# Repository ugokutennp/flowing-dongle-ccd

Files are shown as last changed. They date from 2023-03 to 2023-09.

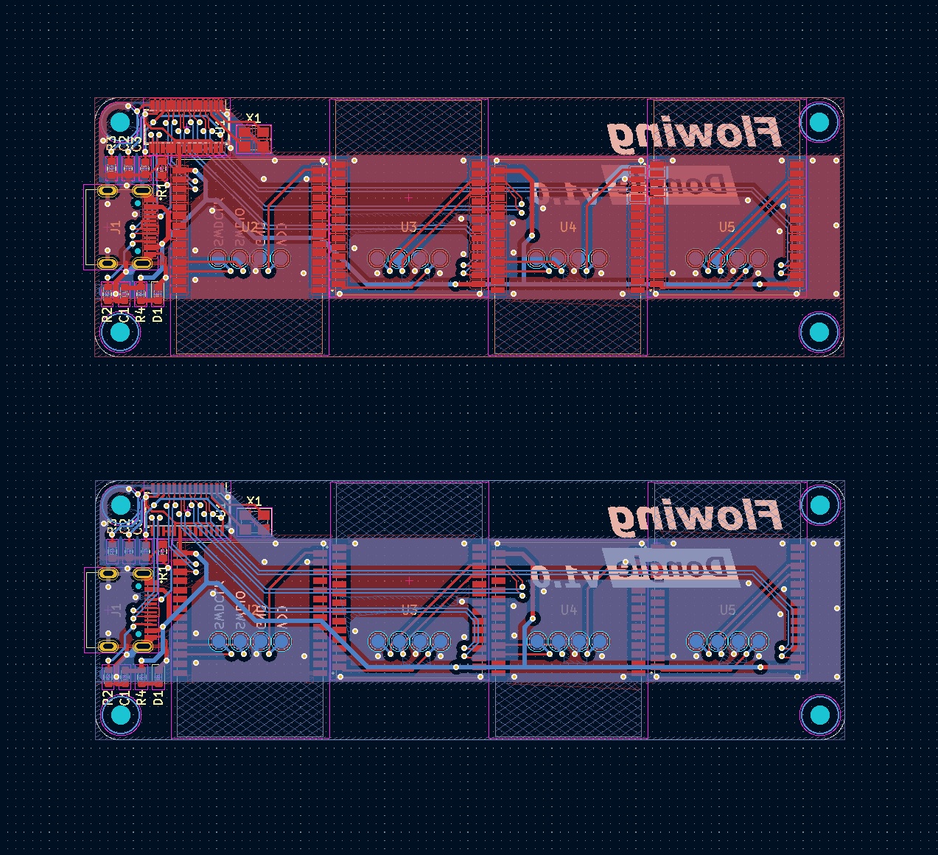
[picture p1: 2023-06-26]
images/flowing_dongle_pcb.jpg

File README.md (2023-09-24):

# FlowingDongleCCD
DIY Multiple Connection Watchman Dongle for SteamVR
dongle
FlowingDongle is a very simple dongle for SteamVR that can connect four devices simultaneously with a built-in nrf52840 module and a USB hub.
## Hardware
Includes PCB data created in kicad6 and 3D model data of the case.
The main components are made of the following.
|| components |
|--|--|
| USB 2.0 Hub Controller |FE1.1s  |
|nrf52840 module| MS88SF2 |

BOM can be viewed [here](https://htmlpreview.github.io/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).
The PCB design and schematic is minimal and not perfect, although stable operation has been confirmed.

[schematic](https://github.com/ugokutennp/FlowingDongleCCD/blob/main/images/flowing_dongle_schematic.pdf),
[pcb_design](https://github.com/ugokutennp/FlowingDongleCCD/blob/main/images/flowing_dongle_pcb.jpg)

## Firmware
By writing the four hex files via SWD using a device such as Jlink, it can be used immediately as a Watchman Dongle.
Firmware comes from the following locations.
| |  name |  place |
|---|---|---|
| Bootloader  |  nrf52840_xxaa_debug.hex |  nRF5_SDK_17.1.0_ddde560\examples\dfu\open_bootloader\pca10056_usb_debug\armgcc |
|  MBR |  mbr_nrf52_2.4.1_mbr.hex | nRF5_SDK_17.1.0_ddde560\components\softdevice\mbr\hex  | 
|  SoftDevice |  s140_nrf52_6.1.1_softdevice.bin |  C:\Program Files (x86)\Steam\steamapps\common\SteamVR\drivers\indexhmd\resources\firmware\radio\gd_1558748372_dfu | 
| Application  |  temp_app_stamped.bin |  C:\Program Files (x86)\Steam\steamapps\common\SteamVR\drivers\indexhmd\resources\firmware\radio\gd_1558748372_dfu | 

## Bootloader build
Install [Make for Windows](https://gnuwin32.sourceforge.net/packages/make.htm) and Arm Embedded Toolchain ([gcc-arm-none-eabi-9-2020-q2-update-win32.exe](https://developer.arm.com/downloads/-/gnu-rm)) and build with the following command.

    cd Desktop\nRF5_SDK_17.1.0_ddde560\examples\dfu\open_bootloader\pca10056_usb_debug\armgcc
    make

## IndexHMD firmware optimization
Open temp_app_stamped.bin with a hex editor and edit the following items.
| adress  |  before |  after | effect |
|---|---|---|---|
| 0x1839D  |  B1|B9 |disable index audio device |
|  0x162E0 |  Valve VR Radio | any string you like| rename USB device|

## Firmware conversion (bin to hex)
Convert firmware using [srec_cat_exe](https://sourceforge.net/projects/srecord/files/srecord-win32/).

    cd C:\Users\marim\Desktop\Dongle\gd_1558748372_dfu
    srec_cat.exe s140_nrf52_6.1.1_softdevice.bin -Binary -offset 0x1000 -o s140_nrf52_6.1.1_softdevice.hex -Intel
    srec_cat.exe temp_app_stamped.bin -Binary -offset 0x26000 -o temp_app_stamped.hex -Intel
## License
The license applies to hardware data only.

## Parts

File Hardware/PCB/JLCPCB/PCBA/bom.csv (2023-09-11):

Designator | Footprint | Quantity | Value | LCSC Part #
C1, C2, C3 | 0603 | 3 | 10uF
D1 | 0603 | 1 | LED
J1 | HRO_TYPE-C-31-M-12 | 1 | TYPE-C-31-M-12
R1, R2 | 0603 | 2 | 5.1k
R3 | 0603 | 1 | 2.7kΩ(+-1%)
R4 | 0603 | 1 | R
U1 | SSOP-28_3.9x9.9mm_P0.635mm | 1 | FE1.1s
U2, U3, U4, U5 | XCVR_MS88SF2 | 4 | MS88SF2
X1 | Crystal_SMD_3225-4Pin_3.2x2.5mm | 1 | 12MHz

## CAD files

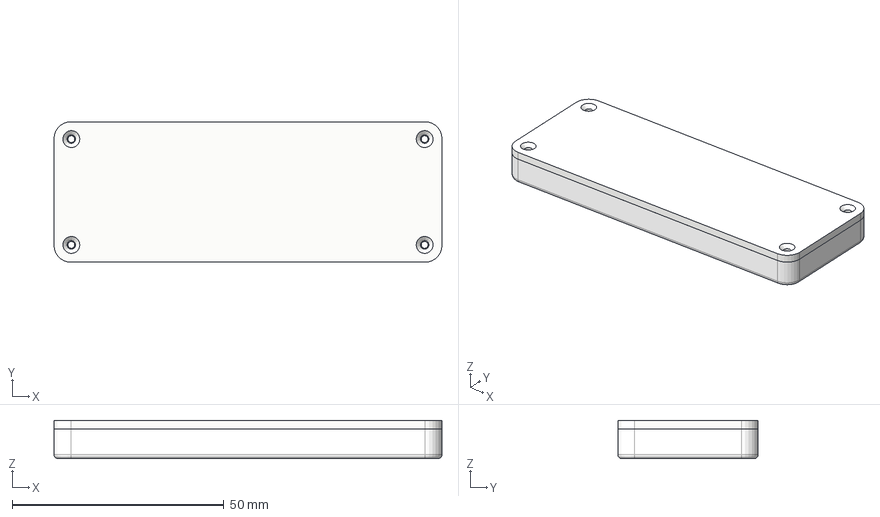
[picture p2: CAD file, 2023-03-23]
Hardware/Case/flowing_dongle v16.step
91.7 x 33.2 x 9.06 mm
_autosave-flowing_dongle PCB

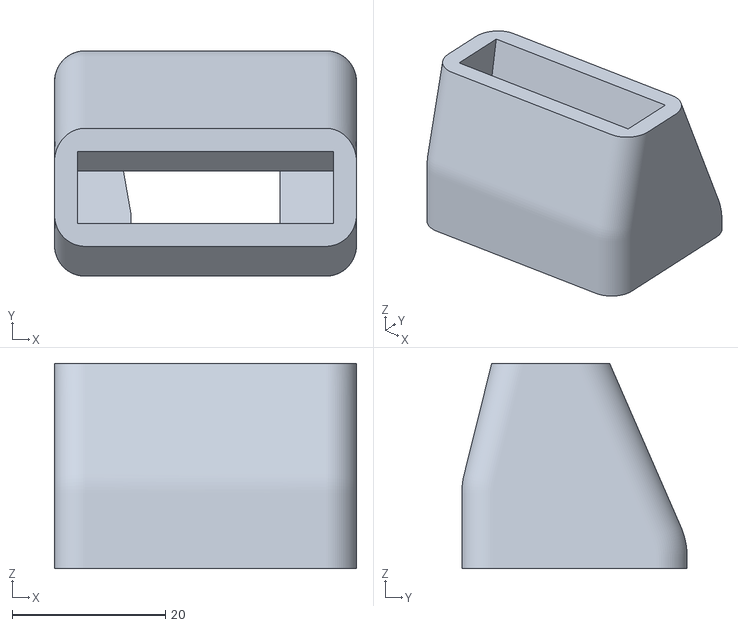
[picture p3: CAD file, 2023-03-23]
Hardware/Case/STL/cradle.stl
39.4 x 29.4 x 26.8

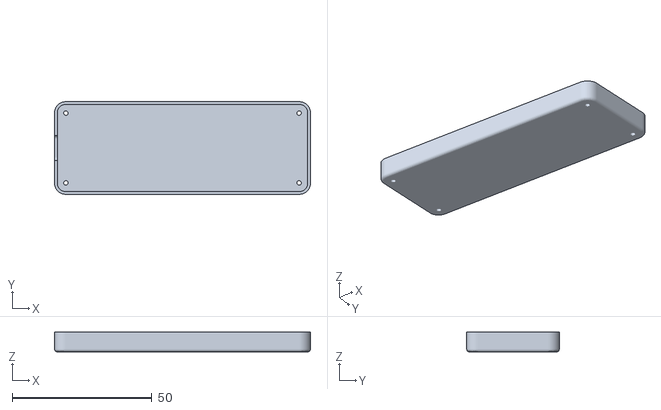
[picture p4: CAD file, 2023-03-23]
Hardware/Case/STL/case.stl
91.7 x 33.2 x 7.06

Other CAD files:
Hardware/Case/cradle v6.step

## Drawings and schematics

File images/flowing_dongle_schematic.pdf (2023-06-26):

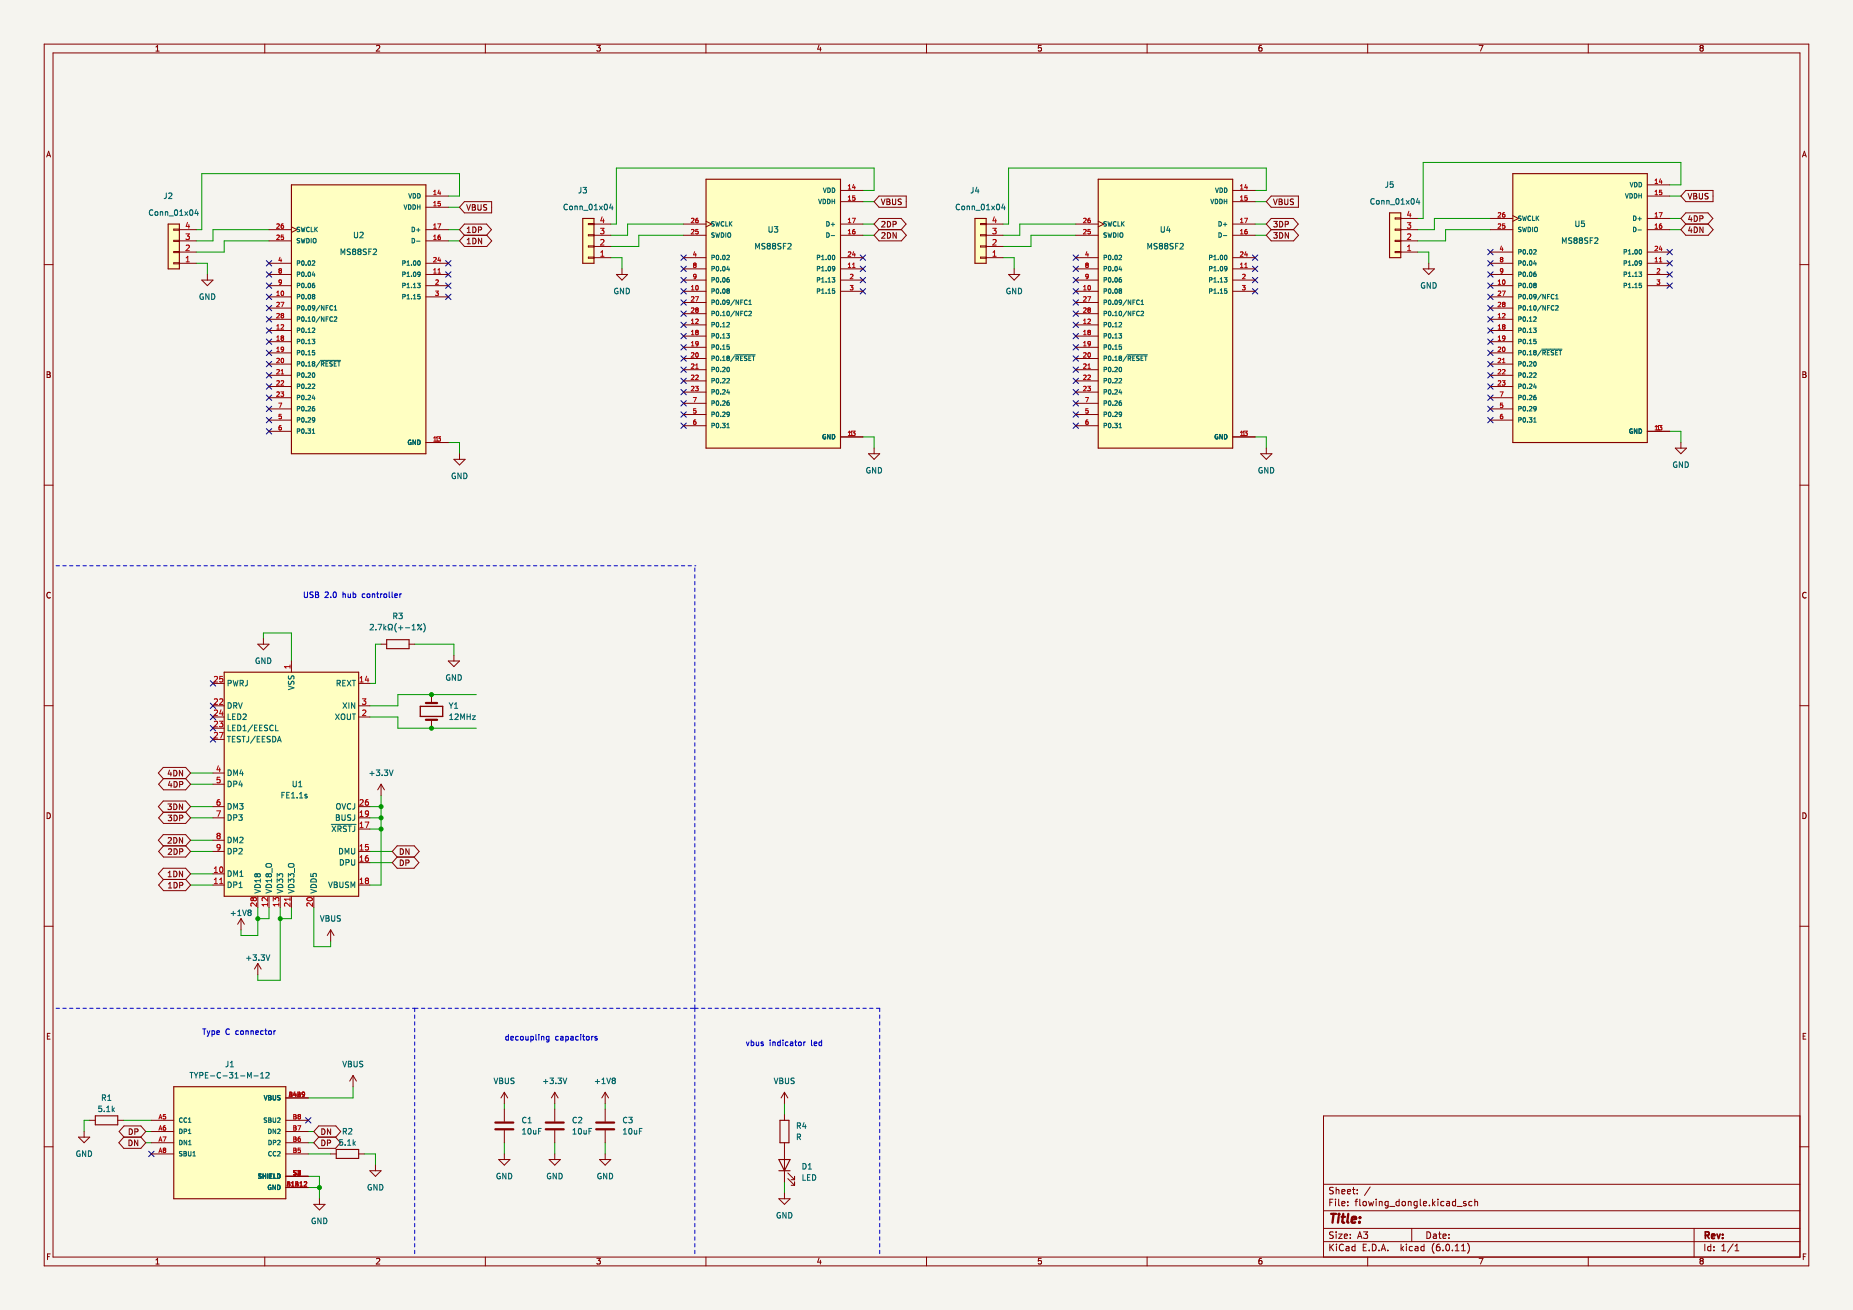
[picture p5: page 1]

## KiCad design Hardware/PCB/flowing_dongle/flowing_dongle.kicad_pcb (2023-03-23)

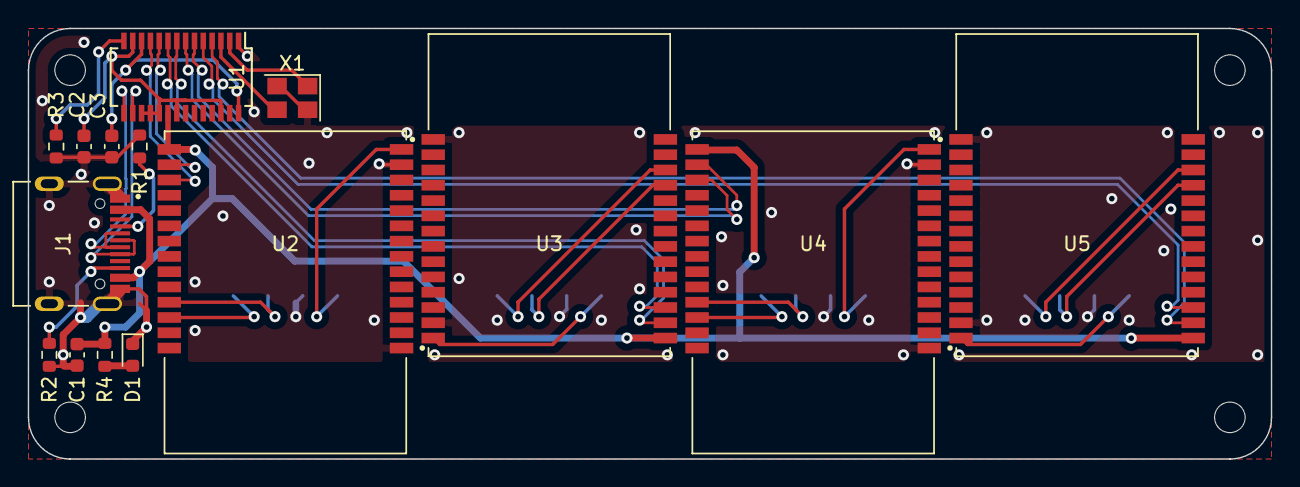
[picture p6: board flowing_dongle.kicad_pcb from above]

Board: 2 copper layers, 89.5 x 31.0 mm, 15 parts (0 on the bottom side), 20 nets.

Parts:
C1, C2, C3: 10uF; C_0603_1608Metric
D1: LED; LED_0603_1608Metric
J1: TYPE-C-31-M-12; HRO_TYPE-C-31-M-12
R1, R2: 5.1k; R_0603_1608Metric
R3: 2.7kΩ(+-1%); R_0603_1608Metric
R4: R; R_0603_1608Metric
U1: FE1.1s; SSOP-28_3.9x9.9mm_P0.635mm
U2, U3, U4, U5: MS88SF2; XCVR_MS88SF2
X1: 12MHz; Crystal_SMD_3225-4Pin_3.2x2.5mm

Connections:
1DN: U1.10 (DM1), U2.16 (D-)
1DP: U1.11 (DP1), U2.17 (D+)
2DN: U1.8 (DM2), U3.16 (D-)
2DP: U1.9 (DP2), U3.17 (D+)
3DN: U1.6 (DM3), U4.16 (D-)
3DP: U1.7 (DP3), U4.17 (D+)
4DN: U1.4 (DM4), U5.16 (D-)
4DP: U1.5 (DP4), U5.17 (D+)
+1V8: C3.1, U1.12 (VD18_O), U1.28 (VD18)
+3.3V: C2.1, U1.13 (VD33), U1.17 (~XRSTJ), U1.18 (VBUSM), U1.19 (BUSJ), U1.21 (VD33_O), U1.26 (OVCJ)
DN: J1.A7 (DN1), J1.B7 (DN2), U1.15 (DMU)
DP: J1.A6 (DP1), J1.B6 (DP2), U1.16 (DPU)
GND: C1.2, C2.2, C3.2, D1.1 (K), J1.A1B12 (GND), J1.B1A12 (GND), J1.S1 (SHIELD), J1.S2 (SHIELD), J1.S3 (SHIELD), J1.S4 (SHIELD), R1.2, R2.1, R3.1, U1.1 (VSS), U2.1 (GND), U2.13 (GND), U3.1 (GND), U3.13 (GND), U4.1 (GND), U4.13 (GND), U5.1 (GND), U5.13 (GND), X1.2, X1.4
unnamed: D1.2 (A), R4.2
unnamed: J1.A5 (CC1), R1.1
unnamed: J1.B5 (CC2), R2.2
unnamed: R3.2, U1.14 (REXT)
unnamed: U1.2 (XOUT), X1.1
unnamed: U1.3 (XIN), X1.3
VBUS: C1.1, J1.A4B9 (VBUS), J1.B4A9 (VBUS), R4.1, U1.20 (VDD5), U2.15 (VDDH), U3.15 (VDDH), U4.15 (VDDH), U5.15 (VDDH)

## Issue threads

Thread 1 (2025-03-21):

Missing Resistor R4

EnricoKlasen, 2025-03-21:
Hello,

I'm having issues with the PCB, can you tell me what resistor value is used for R4?

Best Regards,
Enrico

EnricoKlasen, 2025-03-21:
Thanks a lot. I hope that ill get my assembly soon.

Closed 2025-03-21.
